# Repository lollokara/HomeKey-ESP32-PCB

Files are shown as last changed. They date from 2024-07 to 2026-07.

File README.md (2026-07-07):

<div align="center">

# HomeKey-ESP32-PCB

**A miniaturized, wall-mountable HomeKey reader board**

A custom PCB implementation of [rednblkx/HomeKey-ESP32](https://github.com/rednblkx/HomeKey-ESP32) that brings Apple HomeKey NFC unlocking into a form factor small enough to hide behind your existing wall plate.



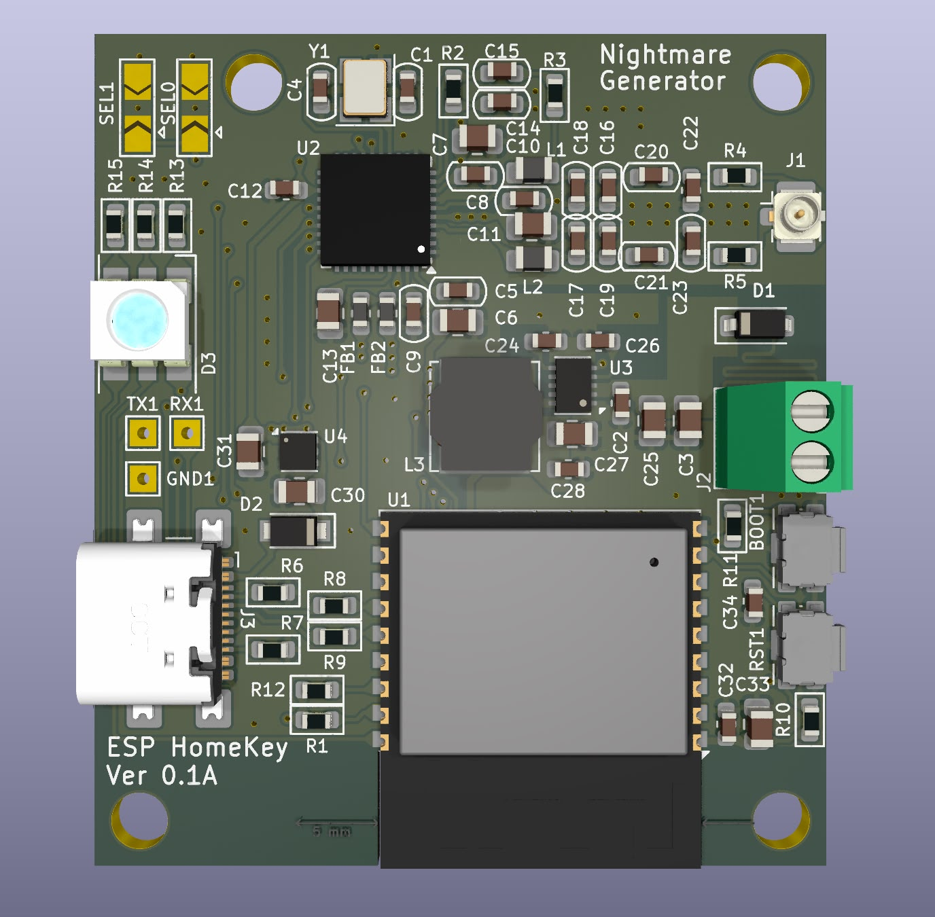
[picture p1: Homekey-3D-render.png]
HomeKey-ESP32-PCB 3D render


</div>

## What is this?

This project is a **hardware redesign** of the excellent [HomeKey-ESP32](https://github.com/rednblkx/HomeKey-ESP32) firmware by [@rednblkx](https://github.com/rednblkx). Instead of using a separate development board wired to a breakout PN532 module, everything is integrated onto a single, compact PCB.

The board packs an **ESP32-C3** and an **NFC reader front-end with an on-board coaxial NFC antenna** into a footprint designed to fit inside a **European 503 (3-module) flush-mount wall box**. This lets you install a fully functional Apple HomeKey reader directly behind a standard wall plate — no external modules, no messy wiring.

## Key Highlights

- **All-in-one PCB** — ESP32-C3 + NFC front-end + coaxial antenna on a single board
- **Fits a European 503 plug slot** — designed for standard flush-mount wall boxes
- **Integrated coaxial NFC antenna** — tuned on-board antenna, no external coil needed
- **Runs the original HomeKey-ESP32 firmware** — full Apple HomeKey / HomeKit compatibility
- **Fully open hardware** — designed in **KiCad**, with schematics, layout, Gerbers and a 3D model included

## Get the Board

Don't want to fabricate it yourself? You can order the PCB directly from PCBWay:

**➡️ [ESP32 HomeKey on PCBWay](https://www.pcbway.com/project/shareproject/ESP32_Homekey_77a119d7.html)**

## Designed in KiCad

The entire board is designed with **[KiCad](https://www.kicad.org/)**, so the complete hardware source is open and editable. The repository includes:

- Hierarchical KiCad schematics (`Homekey.kicad_sch`, `ESP32.kicad_sch`, `NFC.kicad_sch`, `Power.kicad_sch`, `Square.kicad_sch`)
- KiCad PCB layout (`Homekey.kicad_pcb`) and project file (`Homekey.kicad_pro`)
- Exported schematic PDF (`Homekey.pdf`)
- Bill of Materials (`Homekey.xlsx`)
- A 3D model of the assembly (`Homekey 3D.step.zip`)

You can open the project directly in KiCad to review, modify, or re-fabricate the board.

## Repository Structure

```
HomeKey-ESP32-PCB/
├── Firmware/              # HomeKey-ESP32 firmware (based on the original repo)
├── Gerbers/               # Fabrication-ready Gerber files
├── ESP32.kicad_sch        # ESP32-C3 subsheet
├── NFC.kicad_sch          # NFC front-end + antenna subsheet
├── Power.kicad_sch        # Power supply subsheet
├── Square.kicad_sch       # Additional subsheet
├── Homekey.kicad_sch      # Top-level schematic
├── Homekey.kicad_pcb      # PCB layout
├── Homekey.kicad_pro      # KiCad project file
├── Homekey.pdf            # Schematic (PDF export)
├── Homekey.xlsx           # Bill of Materials
├── Homekey-job.gbrjob     # Gerber job file
├── Homekey 3D.step.zip    # 3D model of the board
├── Homekey-3D-render.png  # 3D render of the assembled board
└── README.md
```

## Getting Started

### 1. Get the Board

- **Buy it ready-made:** order the PCB directly from [PCBWay](https://www.pcbway.com/project/shareproject/ESP32_Homekey_77a119d7.html).
- **Fabricate it yourself:** use the ready-to-order files in the [`Gerbers`](Gerbers) folder with your preferred PCB fab house.
- Refer to `Homekey.xlsx` for the Bill of Materials and `Homekey.pdf` for the schematic.
- To modify the design first, open `Homekey.kicad_pro` in KiCad.

### 2. Flash the Firmware

The board runs the standard HomeKey-ESP32 firmware. The [`Firmware`](Firmware) folder contains a build based on the original repository.

```bash
# Install esptool (one-time setup)
pip install esptool

# Flash the firmware (replace YOUR_PORT)
esptool.py --port YOUR_PORT write_flash 0x0 firmware.factory.bin
```

> Prefer a GUI? Use the [browser-based flasher](https://espressif.github.io/esptool-js/) — no command line needed.

For firmware configuration, pairing, and usage, follow the official documentation:
- **Docs:** https://rednblkx.github.io/HomeKey-ESP32/
- **Upstream firmware:** https://github.com/rednblkx/HomeKey-ESP32

### 3. Install & Pair

1. Mount the board inside your 503 wall box behind the plate.
2. Connect to the device's setup WiFi AP and configure your WiFi + HomeKit setup code.
3. Pair with Apple Home and start unlocking with a tap of your iPhone or Apple Watch. 🎉

## Credits

- **[@rednblkx](https://github.com/rednblkx)** — creator of the original [HomeKey-ESP32](https://github.com/rednblkx/HomeKey-ESP32) firmware this board is built for
- **[@kormax](https://github.com/kormax)** — reverse-engineered the HomeKey NFC protocol
- **[@kupa22](https://github.com/kupa22)** — researched the HAP side of HomeKey

## License

This project is licensed under the **MIT License** — see the [LICENSE](LICENSE) file for details.

## Disclaimer

This project implements Apple HomeKey functionality through reverse engineering.

- **Not affiliated** with, nor condoned by, Apple Inc.
- **Use at your own risk** for security-critical applications.
- **Apple**, **iPhone**, and **Apple Watch** are trademarks of Apple Inc.
- **ESP32** is a trademark of Espressif Systems (Shanghai) Co., Ltd.

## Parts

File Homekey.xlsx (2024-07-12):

Homekey
Id | Riferimento | Impronta | Quantità | Valore | Produttore | PN
1 | R9,R8 | R_0603_1608Metric | 2 | 22R 1% | Yageo | RC0603FR-0722RL
2 | C22 | C_0603_1608Metric | 1 | 100pF | Samsung | CL10B101KB8NFNC
3 | GND1,RX1,TX1 | TestPoint_THTPad_1.5x1.5mm_Drill0.7mm | 3 | TestPoint
4 | C30,C13,C27,C6,C31,C11,C10,C25,C3,C33 | C_0805_2012Metric | 10 | 10uF | Murata | CAP CER 10UF 50V X5R 0805
5 | R6,R7 | R_0603_1608Metric | 2 | 5K1 1% |  | RC0603FR-075K1L
6 | C15 | C_0603_1608Metric | 1 | 1nF | Kemet | C0603C102K5RAC7867
7 | C4,C1,C21,C20 | C_0603_1608Metric | 4 | 22pF | Kemet | C0603C220J5GAC7867
8 | U3 | TDFN-10-1EP_2x3mm_P0.5mm_EP0.9x2mm | 1 | MAX17501AxTB | Maxim | MAX17501AATB+T
9 | C32,C28,C2,C12 | C_0603_1608Metric | 4 | 100nF | Samsung | CL10B104KB8NNNC
10 | FB1,FB2 | L_0603_1608Metric | 2 | 220R@100Mhz | TDK | MPZ1608S221ATA00
11 | L1,L2 | L_0805_2012Metric | 2 | 560nH | Bourns | CV201210-R56K
12 | C24 | C_0603_1608Metric | 1 | 1nF | Kemet | C0603C102K5RAC7867
13 | D1 | SOD123 | 1 | MBR0560-TP | MCC | MBR0560-TP
14 | C7,C8,C5,C9,C14 | C_0603_1608Metric | 5 | 100nF | Samsung | CL10B104KB8NNNC
15 | R2 | R_0603_1608Metric | 1 | 1K 1% |  | RC0603FR-071K0L
16 | R11,R1,R10,R12 | R_0603_1608Metric | 4 | 10K |  | RC0603FR-0710KL
17 | C17,C16 | C_0603_1608Metric | 2 | 220pF | Samsung | CL10B221KB8NFNC
18 | RST1,BOOT1 | SW_SPST_CK_KMS2xxGP | 2 | CK_KMS2xxG | CK | KMS221GPLFS
19 | C19,C18 | C_0603_1608Metric | 2 | NC
20 | J1 | U.FL_Hirose_U.FL-R-SMT-1_Vertical | 1 | Hirose | Hirose | U.FL-R-SMT-1(32)
21 | U2 | HVQFN-40-1EP_6x6mm_P0.5mm_EP4.1x4.1mm | 1 | PN5321A3HN_C1xx | NXP | PN5321A3HN/C106,55
22 | R15,R13 | R_0603_1608Metric | 2 | 75R |  | RC0603FR-0775RL
23 | C26,C34 | C_0603_1608Metric | 2 | 1uF | Samsung | CL10B105KP8NNNC
24 | R5,R4 | R_0603_1608Metric | 2 | 1R5 1% |  | RC0603FR-071R5L
25 | L3 | L_Bourns_SRN6045TA | 1 | 33uH | Bourns | SRN6045TA-330M
26 | D2 | Nexperia_CFP3_SOD-123W | 1 | PMEG2010BER | Nexperia | PMEG2010BER
27 | D3 | LED_Inolux_IN-P55TATRGB_PLCC6_5.0x5.5mm_P1.8mm | 1 | Inolux_IN-P55TATRGB | Inolux | IN-P55TATRGB
28 | U4 | WSON-6-1EP_2x2mm_P0.65mm_EP1x1.6mm | 1 | TLV75533PDRV | Texas Instruments | TLV75533PDRV
29 | C23 | C_0603_1608Metric | 1 | 100pF | Samsung | CL10B101KB8NFNC
30 | J2 | TerminalBlock_Phoenix_MPT-0,5-2-2.54_1x02_P2.54mm_Horizontal | 1 | Screw_Terminal_01x02 | Phoenix | 1725656
31 | R14 | R_0603_1608Metric | 1 | 150R |  | RC0603FR-07150RL
32 | U1 | ESP32-C3-WROOM-02 | 1 | ESP32-C3-WROOM-02 | Espressif | ESP32-C3-WROOM-02-N4
33 | J3 | USB_C_Receptacle_GCT_USB4110 | 1 | USB_C_Receptacle_USB2.0_16P | GCT | USB4110-GF-A
34 | R3 | R_0603_1608Metric | 1 | 1K69 1% |  | RC0603FR-071K69L
35 | Y1 | Crystal_SMD_3225-4Pin_3.2x2.5mm | 1 | 27.12MHz | Raltron | RH100-27.120-12-F-3030-EXT-TR

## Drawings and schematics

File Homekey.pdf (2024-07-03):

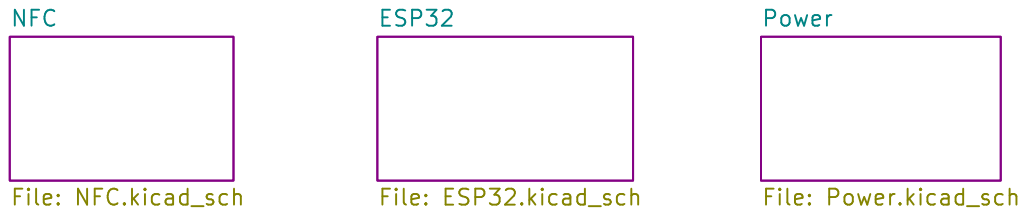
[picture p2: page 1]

File: Homekey.kicad_sch Sheet: /
Id: 1/4 Title: Homekey PCB ESP32C3

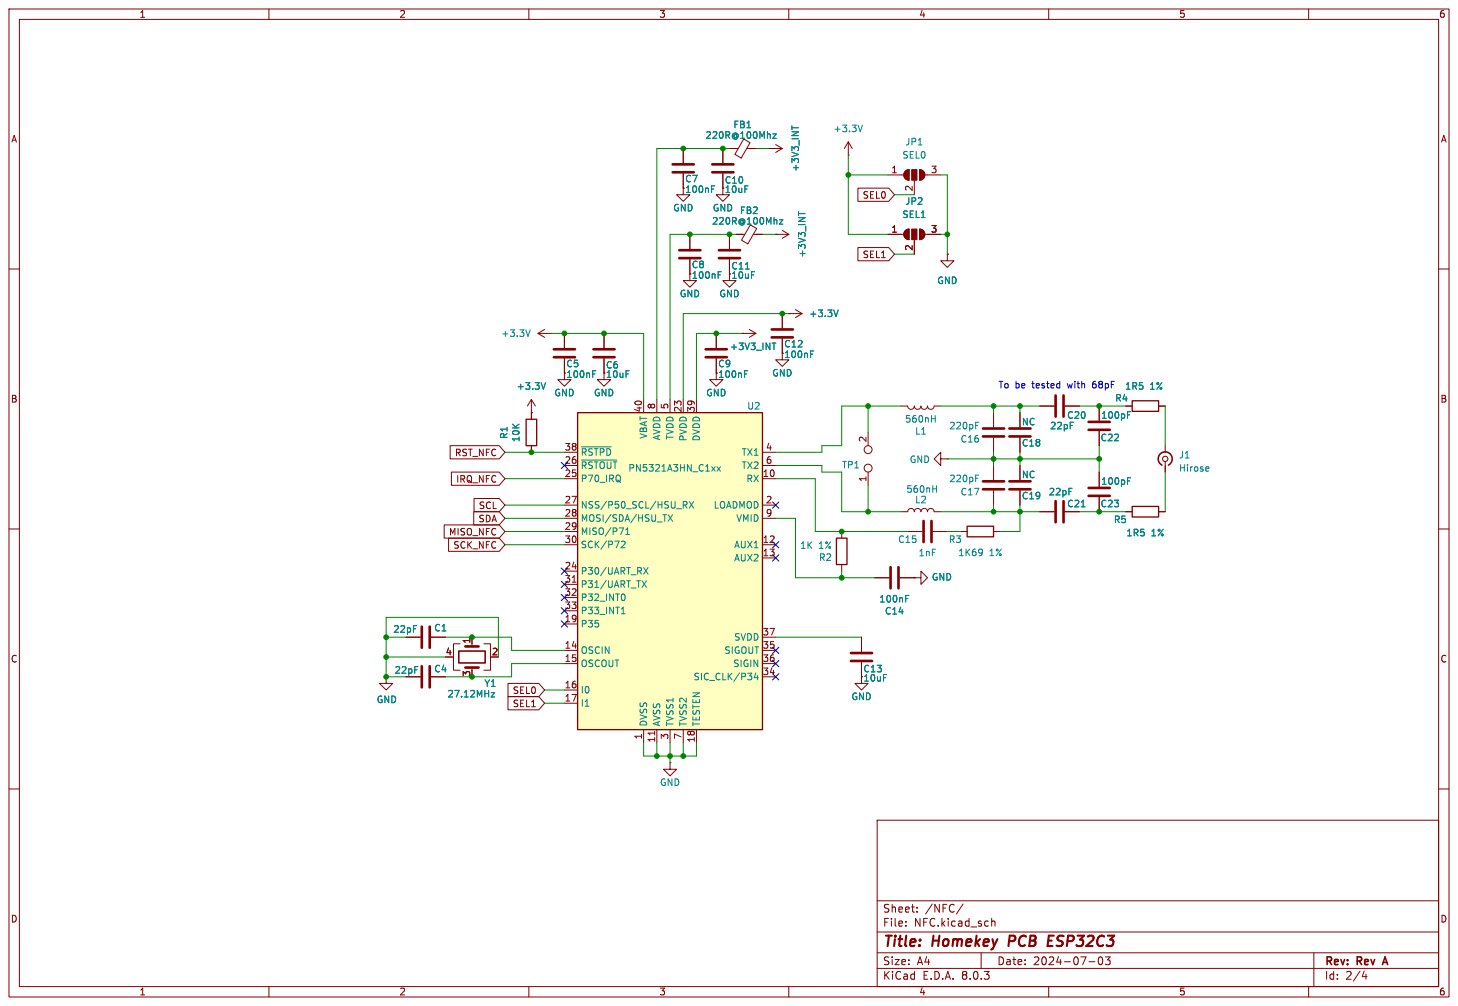
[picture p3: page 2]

Id: 2/4 Title: Homekey PCB ESP32C3

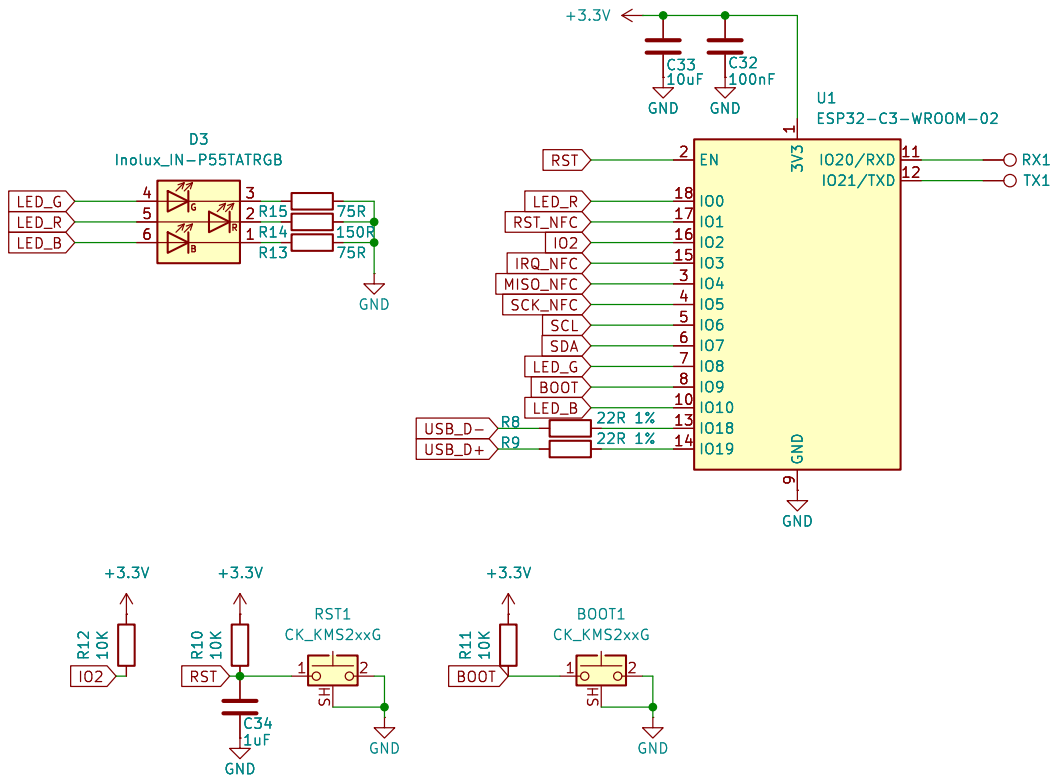
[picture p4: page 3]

Id: 3/4 Title: Homekey PCB ESP32C3

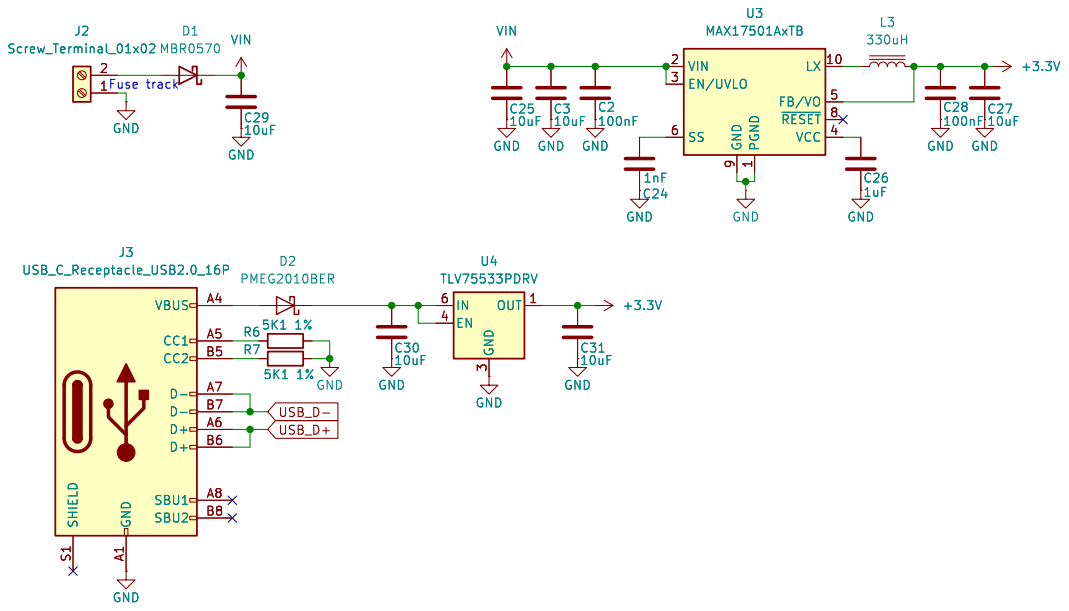
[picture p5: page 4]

File: Power.kicad_sch Sheet: /Power/
Id: 4/4 Title: Homekey PCB ESP32C3

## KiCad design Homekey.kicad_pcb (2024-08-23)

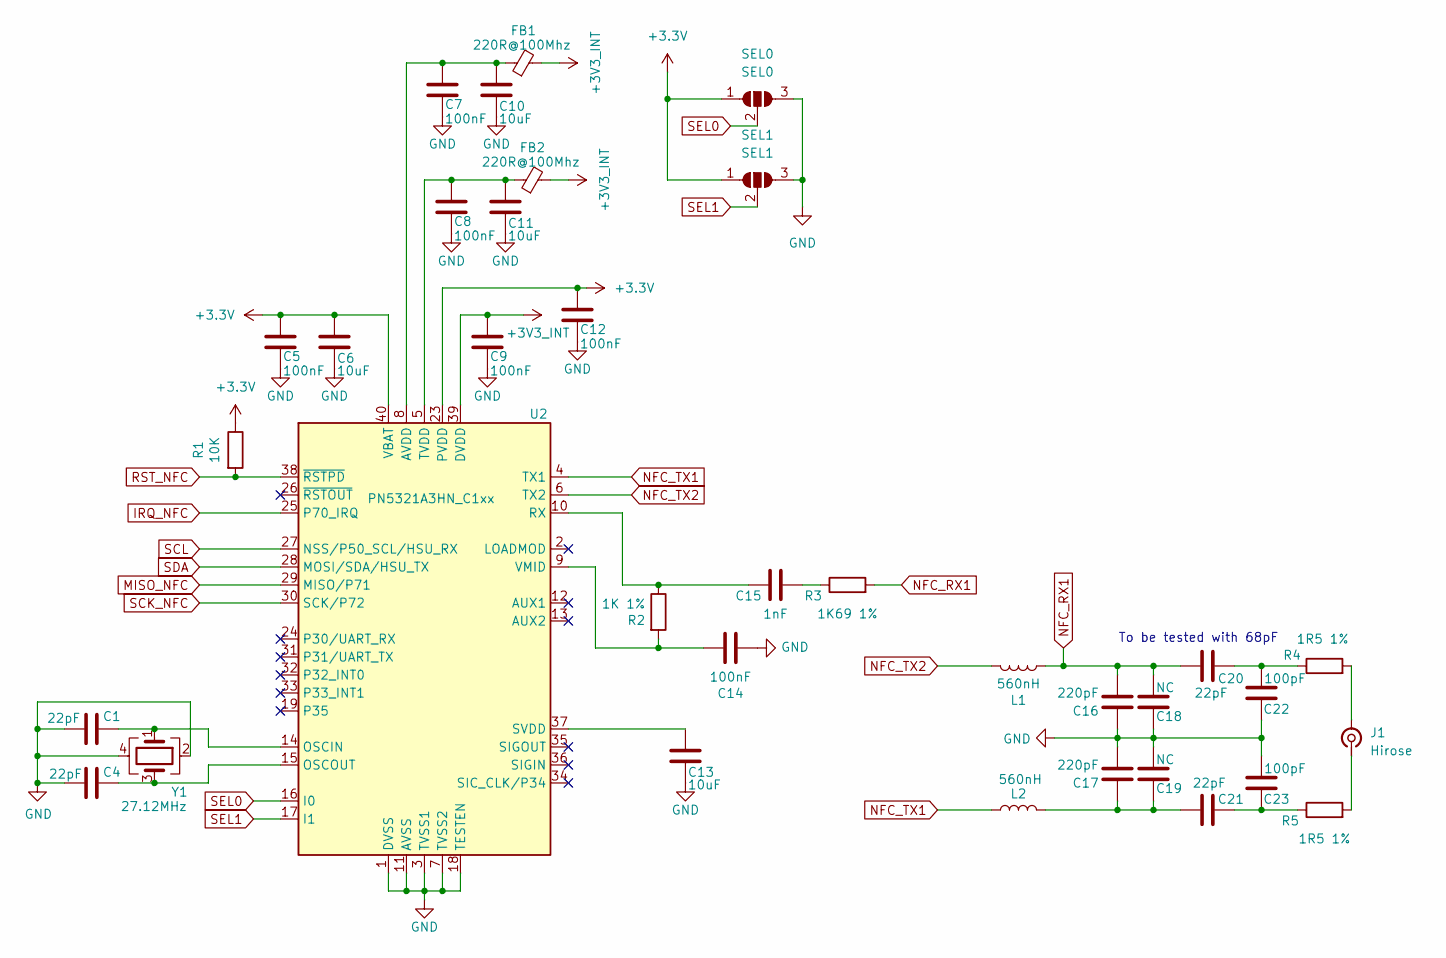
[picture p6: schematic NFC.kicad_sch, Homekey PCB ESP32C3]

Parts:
C1, C4: 22pF; C_0603_1608Metric; Part No 0603-22pF-50V
C5, C7, C8, C9, C12: 100nF; C_0603_1608Metric
C6, C10, C11, C13: 10uF; C_0805_2012Metric
C14: 100nF; C_0603_1608Metric; Part No 0603-100nF-25V
C15: 1nF; C_0603_1608Metric; Part No VJ0603A102GXAPW1BC
C16, C17: 220pF; C_0603_1608Metric; Part No 0603-220pF-50V
C18, C19: NC; C_0603_1608Metric
C20, C21: 22pF; C_0603_1608Metric; Part No 0603N220F500CT
C22, C23: 100pF; C_0603_1608Metric; Part No 0603-100pF-50V
FB1, FB2: 220R@100Mhz; L_0603_1608Metric
J1: Hirose; U.FL_Hirose_U.FL-R-SMT-1_Vertical
L1, L2: 560nH; L_0805_2012Metric; Part No LQW2UASR56G00L
R1: 10K; R_0603_1608Metric; Part No 0603-10K
R2: 1K 1%; R_0603_1608Metric; Part No CRCW06031K00FKEAC
R3: 1K69 1%; R_0603_1608Metric; Part No RC0603FR-101K69L
R4, R5: 1R5 1%; R_0603_1608Metric; Part No CRCW06031R50FKEA
SEL0: SEL0; SolderJumper-3_P2.0mm_Open_TrianglePad1.0x1.5mm
SEL1: SEL1; SolderJumper-3_P2.0mm_Open_TrianglePad1.0x1.5mm
U2: PN5321A3HN_C1xx; HVQFN-40-1EP_6x6mm_P0.5mm_EP4.1x4.1mm
Y1: 27.12MHz; Crystal_SMD_3225-4Pin_3.2x2.5mm; Part No ABM81-27.120MHZ-10-B1U-T3

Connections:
+3.3V: C5.2, C6.1, C12.2, R1.1, SEL0.1 (A), SEL1.1 (A), U2.23 (PVDD), U2.40 (VBAT); also elsewhere on the board
+3V3_INT: C9.2, FB1.2, FB2.2, U2.39 (DVDD)
GND: C1.2, C4.2, C5.1, C6.2, C7.1, C8.1, C9.1, C10.2, C11.2, C12.1, C13.2, C14.2, C16.1, C17.1, C18.1, C19.2, C22.1, C23.2, SEL0.3 (B), SEL1.3 (B), U2.1 (DVSS), U2.3 (TVSS1), U2.7 (TVSS2), U2.11 (AVSS), U2.18 (TESTEN), U2.41 (AVSS), Y1.2, Y1.4; also elsewhere on the board
IRQ_NFC: U2.25 (P70_IRQ); also elsewhere on the board
MISO_NFC: U2.29 (MISO/P71); also elsewhere on the board
NFC_RX1: C16.2, C18.2, C20.1, L1.1, R3.2
NFC_TX1: L2.1, U2.4 (TX1)
NFC_TX2: L1.2, U2.6 (TX2)
unnamed: C15.2, R3.1
unnamed: C17.2, C19.1, C21.1, L2.2
unnamed: C20.2, C22.2, R4.1
unnamed: C21.2, C23.1, R5.1
unnamed: J1.2 (Ext), R4.2
unnamed: J1.1 (In), R5.2
unnamed: C7.2, C10.1, FB1.1, U2.8 (AVDD)
unnamed: C1.1, U2.14 (OSCIN), Y1.1
unnamed: C4.1, U2.15 (OSCOUT), Y1.3
unnamed: C15.1, R2.1, U2.10 (RX)
unnamed: C13.1, U2.37 (SVDD)
unnamed: C8.2, C11.1, FB2.1, U2.5 (TVDD)
unnamed: C14.1, R2.2, U2.9 (VMID)
RST_NFC: R1.2, U2.38 (~RSTPD); also elsewhere on the board
SCK_NFC: U2.30 (SCK/P72); also elsewhere on the board
SCL: U2.27 (NSS/P50_SCL/HSU_RX); also elsewhere on the board
SDA: U2.28 (MOSI/SDA/HSU_TX); also elsewhere on the board
SEL0: SEL0.2 (C), U2.16 (I0)
SEL1: SEL1.2 (C), U2.17 (I1)

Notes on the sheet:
To be tested with 68pF

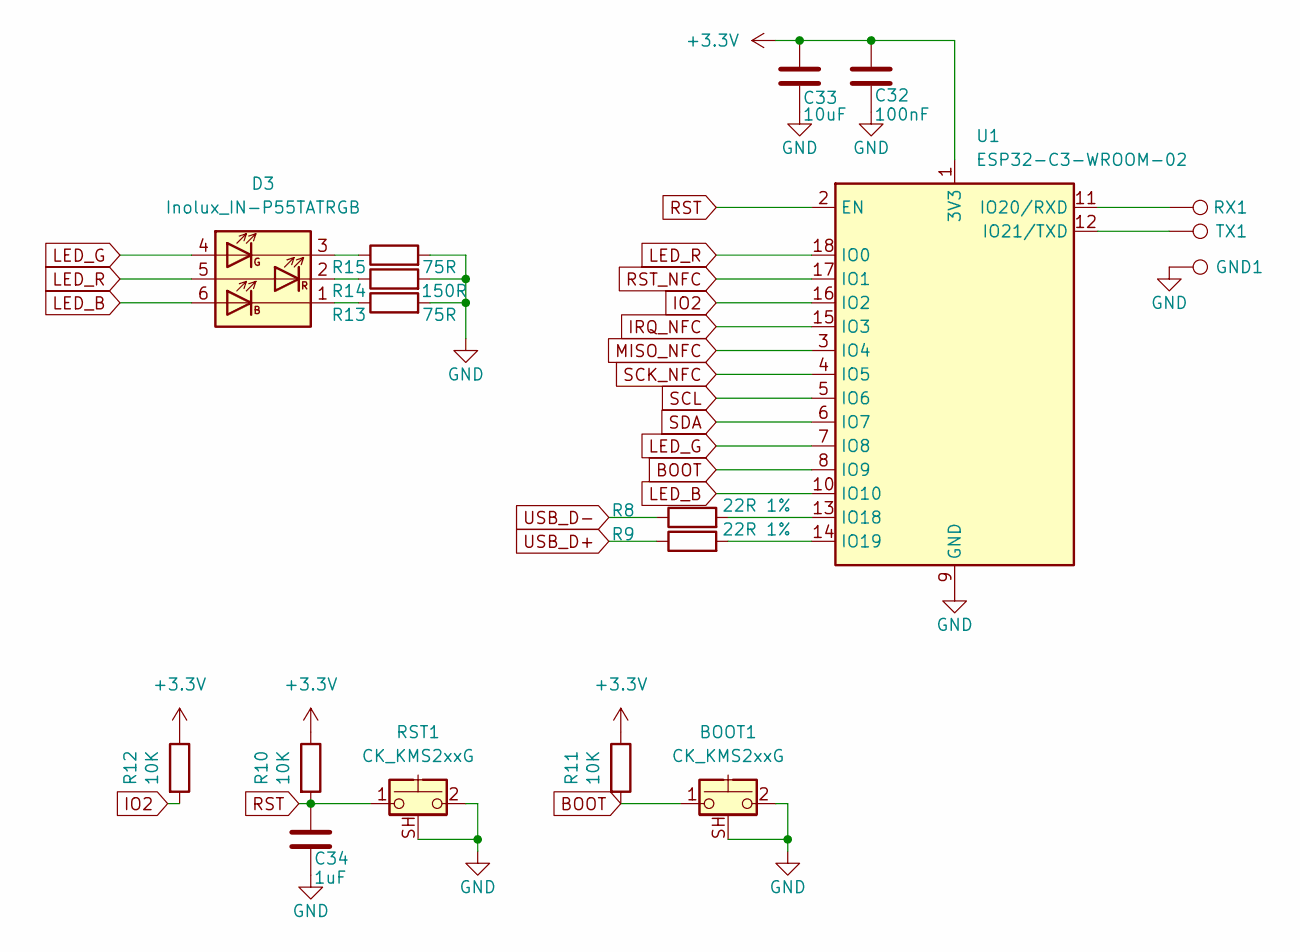
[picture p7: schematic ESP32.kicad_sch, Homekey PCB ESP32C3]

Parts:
BOOT1: CK_KMS2xxG; SW_SPST_CK_KMS2xxGP
C32: 100nF; C_0603_1608Metric
C33: 10uF; C_0805_2012Metric
C34: 1uF; C_0603_1608Metric
D3: Inolux_IN-P55TATRGB; LED_Inolux_IN-P55TATRGB_PLCC6_5.0x5.5mm_P1.8mm
GND1: TestPoint; TestPoint_THTPad_1.5x1.5mm_Drill0.7mm
R8, R9: 22R 1%; R_0603_1608Metric; Part No RC0603FR-1022RL
R10, R11, R12: 10K; R_0603_1608Metric; Part No 0603-10K
R13, R15: 75R; R_0603_1608Metric; Part No RC0603FR-0775RL
R14: 150R; R_0603_1608Metric; Part No RC0603JR-07160RL
RST1: CK_KMS2xxG; SW_SPST_CK_KMS2xxGP
RX1: TestPoint; TestPoint_THTPad_1.5x1.5mm_Drill0.7mm
TX1: TestPoint; TestPoint_THTPad_1.5x1.5mm_Drill0.7mm
U1: ESP32-C3-WROOM-02

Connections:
+3.3V: C32.2, C33.1, R10.1, R11.1, R12.1, U1.1 (3V3); also elsewhere on the board
BOOT: BOOT1.1, R11.2, U1.8 (IO9)
GND: BOOT1.2, BOOT1.SH (B), C32.1, C33.2, C34.1, GND1.1, R13.2, R14.2, R15.2, RST1.2, RST1.SH (B), U1.9 (GND), U1.19 (GND); also elsewhere on the board
IO2: R12.2, U1.16 (IO2)
IRQ_NFC: U1.15 (IO3); also elsewhere on the board
LED_B: D3.6 (AB), U1.10 (IO10)
LED_G: D3.4 (AG), U1.7 (IO8)
LED_R: D3.5 (AR), U1.18 (IO0)
MISO_NFC: U1.3 (IO4); also elsewhere on the board
unnamed: D3.1 (KB), R13.1
unnamed: D3.3 (KG), R15.1
unnamed: D3.2 (KR), R14.1
unnamed: R8.2, U1.13 (IO18)
unnamed: R9.2, U1.14 (IO19)
unnamed: RX1.1, U1.11 (IO20/RXD)
unnamed: TX1.1, U1.12 (IO21/TXD)
RST: C34.2, R10.2, RST1.1, U1.2 (EN)
RST_NFC: U1.17 (IO1); also elsewhere on the board
SCK_NFC: U1.4 (IO5); also elsewhere on the board
SCL: U1.5 (IO6); also elsewhere on the board
SDA: U1.6 (IO7); also elsewhere on the board
USB_D+: R9.1; also elsewhere on the board
USB_D-: R8.1; also elsewhere on the board

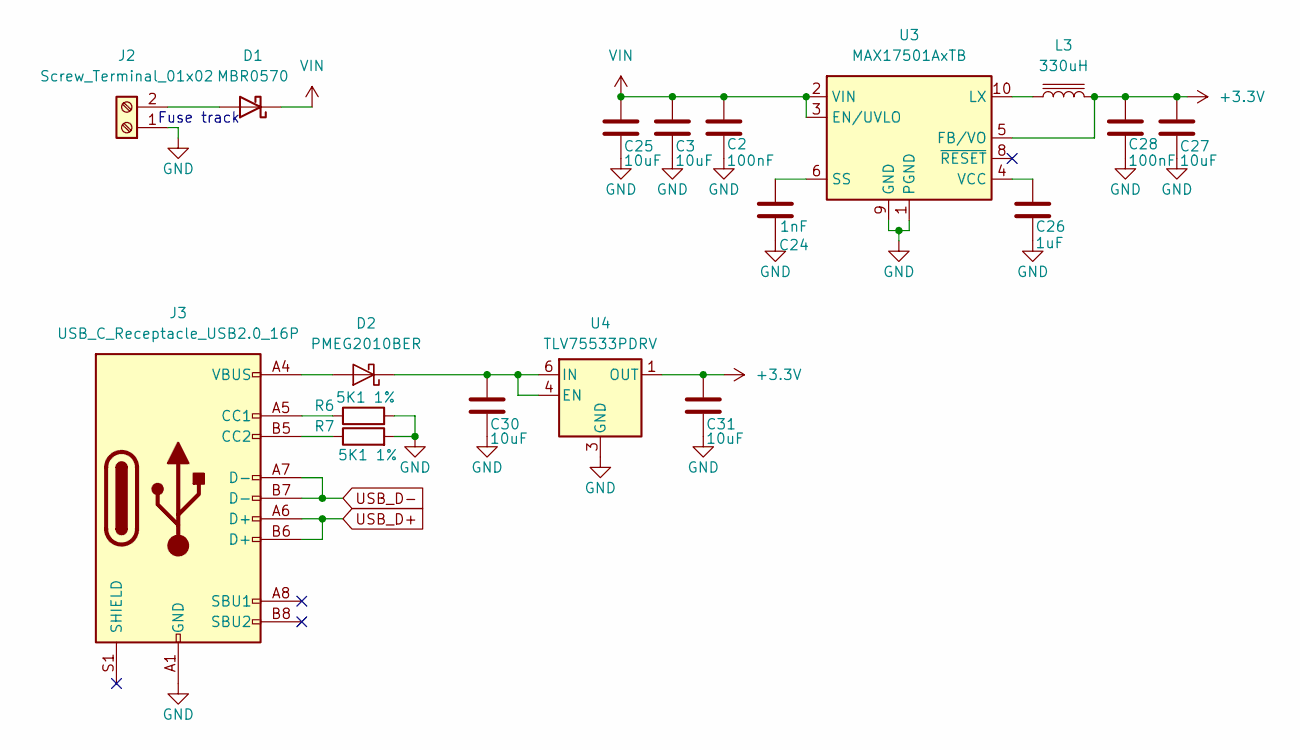
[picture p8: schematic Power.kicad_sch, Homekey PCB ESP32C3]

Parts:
C2, C28: 100nF; C_0603_1608Metric
C3, C25, C27, C30, C31: 10uF; C_0805_2012Metric
C24: 1nF; C_0603_1608Metric; Part No VJ0603A102GXAPW1BC
C26: 1uF; C_0603_1608Metric
D1: MBR0570; Fuseholder_Littelfuse_Nano2_157x
D2: PMEG2010BER; Nexperia_CFP3_SOD-123W
J2: Screw_Terminal_01x02; TerminalBlock_Phoenix_MPT-0,5-2-2.54_1x02_P2.54mm_Horizontal
J3: USB_C_Receptacle_USB2.0_16P; USB_C_Receptacle_GCT_USB4110
L3: 330uH; L_Bourns_SRN6045TA
R6, R7: 5K1 1%; R_0603_1608Metric; Part No RC0603FR-105K1L
U3: MAX17501AxTB; TDFN-10-1EP_2x3mm_P0.5mm_EP0.9x2mm
U4: TLV75533PDRV; WSON-6-1EP_2x2mm_P0.65mm_EP1x1.6mm

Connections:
+3.3V: C27.1, C28.2, C31.1, L3.2, U3.5 (FB/VO), U4.1 (OUT); also elsewhere on the board
GND: C2.1, C3.2, C24.1, C25.2, C26.1, C27.2, C28.1, C30.2, C31.2, J2.1, J3.A1 (GND), J3.A12 (GND), J3.B1 (GND), J3.B12 (GND), R6.2, R7.2, U3.1 (PGND), U3.9 (GND), U3.11 (GND), U4.3 (GND), U4.7 (GND); also elsewhere on the board
unnamed: D1.2 (A), J2.2
unnamed: D2.2 (A), J3.A4 (VBUS), J3.A9 (VBUS), J3.B4 (VBUS), J3.B9 (VBUS)
unnamed: C30.1, D2.1 (K), U4.4 (EN), U4.6 (IN)
unnamed: J3.A5 (CC1), R6.1
unnamed: J3.B5 (CC2), R7.1
unnamed: L3.1, U3.10 (LX)
unnamed: C24.2, U3.6 (SS)
unnamed: C26.2, U3.4 (VCC)
USB_D+: J3.A6 (D+), J3.B6 (D+); also elsewhere on the board
USB_D-: J3.A7 (D-), J3.B7 (D-); also elsewhere on the board
VIN: C2.2, C3.1, C25.1, D1.1 (K), U3.2 (VIN), U3.3 (EN/UVLO)

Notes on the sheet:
Fuse track

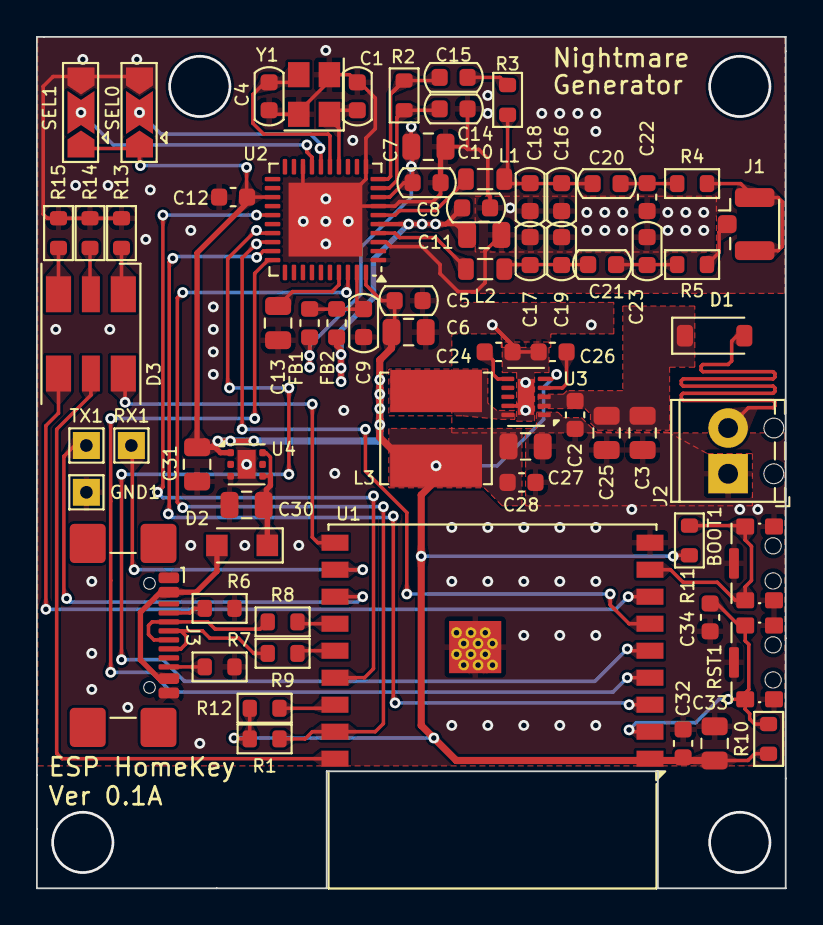
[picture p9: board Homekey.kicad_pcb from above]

Board: 2 copper layers, 41.6 x 47.3 mm, 71 parts (0 on the bottom side), 51 nets.

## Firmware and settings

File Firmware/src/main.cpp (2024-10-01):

#include <hkAuthContext.h>
#include <HomeKey.h>
#include <utils.h>
#include <HomeSpan.h>
#include <PN532_SPI.h>
#include <PN532.h>
#include <HAP.h>
#include <chrono>
#include <AsyncTCP.h>
#include <ESPAsyncWebServer.h>
#include <LittleFS.h>
#include <HK_HomeKit.h>
#include "config.h"
#include <mqtt_client.h>
#include <esp_ota_ops.h>
#include <esp_task.h>
#include <pins_arduino.h>
#include <Adafruit_NeoPixel.h>

const char* TAG = "MAIN";

enum lockStates
{
  UNLOCKED,
  LOCKED,
  JAMMED,
  UNKNOWN,
  UNLOCKING,
  LOCKING
};
AsyncWebServer webServer(80);
PN532_SPI pn532spi(6, 5, 4, 7);
PN532 nfc(pn532spi);
QueueHandle_t gpio_led_handle = nullptr;

nvs_handle savedData;
readerData_t readerData;
uint8_t ecpData[18] = { 0x6A, 0x2, 0xCB, 0x2, 0x6, 0x2, 0x11, 0x0 };
std::map<HK_COLOR, const char*> hk_color_vals = {{TAN, "AQTO1doA"}, {GOLD, "AQSq1uwA"}, {SILVER, "AQTj4+MA"}, {BLACK, "AQQAAAAA"}};
namespace espConfig
{
  struct mqttConfig_t
  {
    /* MQTT Broker */
    std::string mqttBroker = MQTT_HOST;
    uint16_t mqttPort = MQTT_PORT;
    std::string mqttUsername = MQTT_USERNAME;
    std::string mqttPassword = MQTT_PASSWORD;
    std::string mqttClientId = MQTT_CLIENTID;
    /* MQTT Topics */
    std::string hkTopic = MQTT_AUTH_TOPIC;
    std::string lockStateTopic = MQTT_STATE_TOPIC;
    std::string lockStateCmd = MQTT_SET_STATE_TOPIC;
    std::string lockCStateCmd = MQTT_SET_CURRENT_STATE_TOPIC;
    std::string lockTStateCmd = MQTT_SET_TARGET_STATE_TOPIC;
    /* MQTT Custom State */
    std::string lockCustomStateTopic = MQTT_CUSTOM_STATE_TOPIC;
    std::string lockCustomStateCmd = MQTT_CUSTOM_STATE_CTRL_TOPIC;
    /* Flags */
    bool lockEnableCustomState = MQTT_CUSTOM_STATE_ENABLED;
    bool hassMqttDiscoveryEnabled = MQTT_DISCOVERY;
    std::map<std::string, int> customLockStates = {{"C_LOCKED", C_LOCKED}, {"C_UNLOCKING", C_UNLOCKING}, {"C_UNLOCKED", C_UNLOCKED}, {"C_LOCKING", C_LOCKING}, {"C_JAMMED", C_JAMMED}, {"C_UNKNOWN", C_UNKNOWN}};
    std::map<std::string, int> customLockActions = {{"UNLOCK", UNLOCK}, {"LOCK", LOCK}};
  } mqttData;

  struct misc_config_t
  {
    std::string deviceName = DEVICE_NAME;
    std::string otaPasswd = OTA_PWD;
    uint8_t hk_key_color = HOMEKEY_COLOR;
    std::string setupCode = SETUP_CODE;
    bool lockAlwaysUnlock = HOMEKEY_ALWAYS_UNLOCK;
    bool lockAlwaysLock = HOMEKEY_ALWAYS_LOCK;
    uint8_t controlPin = HS_PIN;
    uint8_t hsStatusPin = HS_STATUS_LED;
    uint8_t nfcNeopixelPin = NFC_NEOPIXEL_PIN;
    uint8_t nfcSuccessPin = NFC_SUCCESS_PIN;
    uint16_t nfcSuccessTime = NFC_SUCCESS_TIME;
    bool nfcSuccessHL = NFC_SUCCESS_HL;
    uint8_t nfcFailPin = NFC_FAIL_PIN;
    uint16_t nfcFailTime = NFC_FAIL_TIME;
    bool nfcFailHL = NFC_FAIL_HL;
    bool gpioActionEnable = GPIO_ACTION_ENABLE;
    uint8_t gpioActionPin = GPIO_ACTION_PIN;
    bool gpioActionLockState = GPIO_ACTION_LOCK_STATE;
    bool gpioActionUnlockState = GPIO_ACTION_UNLOCK_STATE;
  } miscConfig;
}
JSONCONS_ALL_MEMBER_TRAITS(espConfig::mqttConfig_t, mqttBroker, mqttPort, mqttUsername, mqttPassword, mqttClientId, hkTopic, lockStateTopic, lockStateCmd, lockCStateCmd, lockTStateCmd, lockCustomStateTopic, lockCustomStateCmd, lockEnableCustomState, hassMqttDiscoveryEnabled, customLockStates, customLockActions)
JSONCONS_ALL_MEMBER_TRAITS(espConfig::misc_config_t, deviceName, hk_key_color, lockAlwaysUnlock, lockAlwaysLock, controlPin, hsStatusPin, nfcSuccessPin, nfcNeopixelPin, nfcSuccessHL, nfcFailPin, nfcFailHL, gpioActionEnable, gpioActionPin, gpioActionLockState, gpioActionUnlockState, otaPasswd, setupCode)

KeyFlow hkFlow = KeyFlow::kFlowFAST;
SpanCharacteristic* lockCurrentState;
SpanCharacteristic* lockTargetState;
esp_mqtt_client_handle_t client = nullptr;

Adafruit_NeoPixel pixels(1, espConfig::miscConfig.nfcNeopixelPin, NEO_GRB + NEO_KHZ800);

bool save_to_nvs() {
  std::vector<uint8_t> cborBuf;
  jsoncons::msgpack::encode_msgpack(readerData, cborBuf);
  esp_err_t set_nvs = nvs_set_blob(savedData, "READERDATA", cborBuf.data(), cborBuf.size());
  esp_err_t commit_nvs = nvs_commit(savedData);
  LOG(D, "NVS SET STATUS: %s", esp_err_to_name(set_nvs));
  LOG(D, "NVS COMMIT STATUS: %s", esp_err_to_name(commit_nvs));
  return !set_nvs && !commit_nvs;
}

struct LockManagement : Service::LockManagement
{
  SpanCharacteristic* lockControlPoint;
  SpanCharacteristic* version;
  const char* TAG = "LockManagement";

  LockManagement() : Service::LockManagement() {

    LOG(D, "Configuring LockManagement"); // initialization message

    lockControlPoint = new Characteristic::LockControlPoint();
    version = new Characteristic::Version();

  } // end constructor

}; // end LockManagement

// Function to calculate CRC16
void crc16a(unsigned char* data, unsigned int size, unsigned char* result) {
  unsigned short w_crc = 0x6363;

  for (unsigned int i = 0; i < size; ++i) {
    unsigned char byte = data[i];
    byte = (byte ^ (w_crc & 0x00FF));
    byte = ((byte ^ (byte << 4)) & 0xFF);
    w_crc = ((w_crc >> 8) ^ (byte << 8) ^ (byte << 3) ^ (byte >> 4)) & 0xFFFF;
  }

  result[0] = static_cast<unsigned char>(w_crc & 0xFF);
  result[1] = static_cast<unsigned char>((w_crc >> 8) & 0xFF);
}

// Function to append CRC16 to data
void with_crc16(unsigned char* data, unsigned int size, unsigned char* result) {
  crc16a(data, size, result);
}

struct LockMechanism : Service::LockMechanism
{
  const char* TAG = "LockMechanism";

  LockMechanism() : Service::LockMechanism() {
    LOG(I, "Configuring LockMechanism"); // initialization message
    lockCurrentState = new Characteristic::LockCurrentState(1, true);
    lockTargetState = new Characteristic::LockTargetState(1, true);
    memcpy(ecpData + 8, readerData.reader_gid.data(), readerData.reader_gid.size());
    with_crc16(ecpData, 16, ecpData + 16);
    if (espConfig::miscConfig.gpioActionEnable && espConfig::miscConfig.gpioActionPin != 255) {
      if (lockCurrentState->getVal() == lockStates::LOCKED) {
        digitalWrite(espConfig::miscConfig.gpioActionPin, espConfig::miscConfig.gpioActionLockState);
      }
      else if (lockCurrentState->getVal() == lockStates::UNLOCKED) {
        digitalWrite(espConfig::miscConfig.gpioActionPin, espConfig::miscConfig.gpioActionUnlockState);
      }
    }
  } // end constructor

  boolean update() {
    int targetState = lockTargetState->getNewVal();
    LOG(I, "New LockState=%d, Current LockState=%d", targetState, lockCurrentState->getVal());
    if (espConfig::miscConfig.gpioActionEnable && espConfig::miscConfig.gpioActionPin != 255) {
      switch (targetState)
      {
        case lockStates::UNLOCKED:
          digitalWrite(espConfig::miscConfig.gpioActionPin, espConfig::miscConfig.gpioActionUnlockState);
          lockCurrentState->setVal(lockStates::UNLOCKED);
          break;

        case lockStates::LOCKED:
          digitalWrite(espConfig::miscConfig.gpioActionPin, espConfig::miscConfig.gpioActionLockState);
          lockCurrentState->setVal(lockStates::LOCKED);
          break;

        default:
          break;
      }
    }
    int currentState = lockCurrentState->getNewVal();
    if (client != nullptr) {
      if (targetState != currentState) {
        esp_mqtt_client_publish(client, espConfig::mqttData.lockStateTopic.c_str(), targetState == lockStates::UNLOCKED ? std::to_string(lockStates::UNLOCKING).c_str() : std::to_string(lockStates::LOCKING).c_str(), 1, 1, true);
      }
      else {
        esp_mqtt_client_publish(client, espConfig::mqttData.lockStateTopic.c_str(), std::to_string(currentState).c_str(), 1, 1, true);
      }
      if (espConfig::mqttData.lockEnableCustomState) {
        if (targetState == lockStates::UNLOCKED) {
          esp_mqtt_client_publish(client, espConfig::mqttData.lockCustomStateTopic.c_str(), std::to_string(espConfig::mqttData.customLockActions["UNLOCK"]).c_str(), 0, 0, false);
        }
        else if (targetState == lockStates::LOCKED) {
          esp_mqtt_client_publish(client, espConfig::mqttData.lockCustomStateTopic.c_str(), std::to_string(espConfig::mqttData.customLockActions["LOCK"]).c_str(), 0, 0, false);
        }
      }
    }
    else LOG(W, "MQTT Client not initialized, cannot publish message");

    return (true);
  }
};

struct NFCAccess : Service::NFCAccess
{
  SpanCharacteristic* configurationState;
  SpanCharacteristic* nfcControlPoint;
  SpanCharacteristic* nfcSupportedConfiguration;
  const char* TAG = "NFCAccess";

  NFCAccess() : Service::NFCAccess() {
    LOG(I, "Configuring NFCAccess"); // initialization message
    configurationState = new Characteristic::ConfigurationState();
    nfcControlPoint = new Characteristic::NFCAccessControlPoint();
    TLV8 conf(NULL, 0);
    conf.add(0x01, 0x10);
    conf.add(0x02, 0x10);
    nfcSupportedConfiguration = new Characteristic::NFCAccessSupportedConfiguration(conf);
  }

  boolean update() {
    LOG(D, "PROVISIONED READER KEY: %s", utils::bufToHexString(readerData.reader_pk.data(), readerData.reader_pk.size()).c_str());
    LOG(D, "READER GROUP IDENTIFIER: %s", utils::bufToHexString(readerData.reader_gid.data(), readerData.reader_gid.size()).c_str());
    LOG(D, "READER UNIQUE IDENTIFIER: %s", utils::bufToHexString(readerData.reader_id.data(), readerData.reader_id.size()).c_str());

    TLV8 ctrlData(NULL, 0);
    nfcControlPoint->getNewTLV(ctrlData);
    std::vector<uint8_t> tlvData(ctrlData.pack_size());
    ctrlData.pack(tlvData.data());
    if (tlvData.size() == 0)
      return false;
    LOG(D, "Decoded data: %s", utils::bufToHexString(tlvData.data(), tlvData.size()).c_str());
    LOG(D, "Decoded data length: %d", tlvData.size());
    HK_HomeKit hkCtx(readerData, savedData, "READERDATA", tlvData);
    std::vector<uint8_t> result = hkCtx.processResult();
    if (readerData.reader_gid.size() > 0) {
      memcpy(ecpData + 8, readerData.reader_gid.data(), readerData.reader_gid.size());
      with_crc16(ecpData, 16, ecpData + 16);
    }
    TLV8 res(NULL, 0);
    res.unpack(result.data(), result.size());
    nfcControlPoint->setTLV(res, false);
    return true;
  }

};

void deleteReaderData(const char* buf) {
  esp_err_t erase_nvs = nvs_erase_key(savedData, "READERDATA");
  esp_err_t commit_nvs = nvs_commit(savedData);
  readerData.issuers.clear();
  readerData.reader_gid.clear();
  readerData.reader_id.clear();
  readerData.reader_pk.clear();
  readerData.reader_pk_x.clear();
  readerData.reader_sk.clear();
  LOG(D, "*** NVS W STATUS");
  LOG(D, "ERASE: %s", esp_err_to_name(erase_nvs));
  LOG(D, "COMMIT: %s", esp_err_to_name(commit_nvs));
  LOG(D, "*** NVS W STATUS");
}

void pairCallback() {
  if (HAPClient::nAdminControllers() == 0) {
    deleteReaderData(NULL);
    return;
  }
  for (auto it = homeSpan.controllerListBegin(); it != homeSpan.controllerListEnd(); ++it) {
    std::vector<uint8_t> id = utils::getHashIdentifier(it->getLTPK(), 32, true);
    LOG(D, "Found allocated controller - Hash: %s", utils::bufToHexString(id.data(), 8).c_str());
    hkIssuer_t* foundIssuer = nullptr;
    for (auto&& issuer : readerData.issuers) {
      if (std::equal(issuer.issuer_id.begin(), issuer.issuer_id.end(), id.begin())) {
        LOG(D, "Issuer %s already added, skipping", utils::bufToHexString(issuer.issuer_id.data(), issuer.issuer_id.size()).c_str());
        foundIssuer = &issuer;
        break;
      }
    }
    if (foundIssuer == nullptr) {
      LOG(D, "Adding new issuer - ID: %s", utils::bufToHexString(id.data(), 8).c_str());
      hkIssuer_t newIssuer;
      newIssuer.issuer_id = std::vector<uint8_t>{id.begin(), id.begin() + 8};
      newIssuer.issuer_pk.insert(newIssuer.issuer_pk.begin(), it->getLTPK(), it->getLTPK() + 32);
      readerData.issuers.emplace_back(newIssuer);
    }
  }
  save_to_nvs();
}

void setFlow(const char* buf) {
  switch (buf[1]) {
  case '0':
    hkFlow = KeyFlow::kFlowFAST;
    Serial.println("FAST Flow");
    break;

  case '1':
    hkFlow = KeyFlow::kFlowSTANDARD;
    Serial.println("STANDARD Flow");
    break;
  case '2':
    hkFlow = KeyFlow::kFlowATTESTATION;
    Serial.println("ATTESTATION Flow");
    break;

  default:
    Serial.println("0 = FAST flow, 1 = STANDARD Flow, 2 = ATTESTATION Flow");
    break;
  }
}

void setLogLevel(const char* buf) {
  esp_log_level_t level = esp_log_level_get("*");
  if (strncmp(buf + 1, "E", 1) == 0) {
    level = ESP_LOG_ERROR;
    Serial.println("ERROR");
  }
  else if (strncmp(buf + 1, "W", 1) == 0) {
    level = ESP_LOG_WARN;
    Serial.println("WARNING");
  }
  else if (strncmp(buf + 1, "I", 1) == 0) {
    level = ESP_LOG_INFO;
    Serial.println("INFO");
  }
  else if (strncmp(buf + 1, "D", 1) == 0) {
    level = ESP_LOG_DEBUG;
    Serial.println("DEBUG");
  }
  else if (strncmp(buf + 1, "V", 1) == 0) {
    level = ESP_LOG_VERBOSE;
    Serial.println("VERBOSE");
  }
  else if (strncmp(buf + 1, "N", 1) == 0) {
    level = ESP_LOG_NONE;
    Serial.println("NONE");
  }

  esp_log_level_set(TAG, level);
  esp_log_level_set("HK_HomeKit", level);
  esp_log_level_set("HKAuthCtx", level);
  esp_log_level_set("HKFastAuth", level);
  esp_log_level_set("HKStdAuth", level);
  esp_log_level_set("HKAttestAuth", level);
  esp_log_level_set("PN532", level);
  esp_log_level_set("PN532_SPI", level);
  esp_log_level_set("ISO18013_SC", level);
  esp_log_level_set("LockMechanism", level);
  esp_log_level_set("NFCAccess", level);
}

void print_issuers(const char* buf) {
  for (auto&& issuer : readerData.issuers) {
    LOG(I, "Issuer ID: %s, Public Key: %s", utils::bufToHexString(issuer.issuer_id.data(), issuer.issuer_id.size()).c_str(), utils::bufToHexString(issuer.issuer_pk.data(), issuer.issuer_pk.size()).c_str());
    for (auto&& endpoint : issuer.endpoints) {
      LOG(I, "Endpoint ID: %s, Public Key: %s", utils::bufToHexString(endpoint.endpoint_id.data(), endpoint.endpoint_id.size()).c_str(), utils::bufToHexString(endpoint.endpoint_pk.data(), endpoint.endpoint_pk.size()).c_str());
    }
  }
}

/**
 * The function `set_custom_state_handler` translate the custom states to their HomeKit counterpart
 * updating the state of the lock and publishes the new state to the `MQTT_STATE_TOPIC` MQTT topic.
 *
 * @param client The `client` parameter in the `set_custom_state_handler` function is of type
 * `esp_mqtt_client_handle_t`, which is a handle to the MQTT client object for this event. This
 * parameter is used to interact with the MQTT client
 * @param state The `state` parameter in the `set_custom_state_handler` function represents the
 *  received custom state value
 */
void set_custom_state_handler(esp_mqtt_client_handle_t client, int state) {
  if(espConfig::mqttData.customLockStates["C_UNLOCKING"] == state){
    lockTargetState->setVal(lockStates::UNLOCKED);
    esp_mqtt_client_publish(client, espConfig::mqttData.lockStateTopic.c_str(), std::to_string(lockStates::UNLOCKING).c_str(), 0, 1, true);
    return;
  }
  else if (espConfig::mqttData.customLockStates["C_LOCKING"] == state) {
    lockTargetState->setVal(lockStates::LOCKED);
    esp_mqtt_client_publish(client, espConfig::mqttData.lockStateTopic.c_str(), std::to_string(lockStates::LOCKING).c_str(), 0, 1, true);
    return;
  }
  else if (espConfig::mqttData.customLockStates["C_UNLOCKED"] == state) {
    if (espConfig::miscConfig.gpioActionEnable && espConfig::miscConfig.gpioActionPin != 0) {
      digitalWrite(espConfig::miscConfig.gpioActionPin, espConfig::miscConfig.gpioActionUnlockState);
    }
    lockCurrentState->setVal(lockStates::UNLOCKED);
    esp_mqtt_client_publish(client, espConfig::mqttData.lockStateTopic.c_str(), std::to_string(lockStates::UNLOCKED).c_str(), 0, 1, true);
    return;
  }
  else if (espConfig::mqttData.customLockStates["C_LOCKED"] == state) {
    if (espConfig::miscConfig.gpioActionEnable && espConfig::miscConfig.gpioActionPin != 0) {
      digitalWrite(espConfig::miscConfig.gpioActionPin, espConfig::miscConfig.gpioActionLockState);
    }
    lockCurrentState->setVal(lockStates::LOCKED);
    esp_mqtt_client_publish(client, espConfig::mqttData.lockStateTopic.c_str(), std::to_string(lockStates::LOCKED).c_str(), 0, 1, true);
    return;
  }
  else if (espConfig::mqttData.customLockStates["C_JAMMED"] == state) {
    lockCurrentState->setVal(lockStates::JAMMED);
    esp_mqtt_client_publish(client, espConfig::mqttData.lockStateTopic.c_str(), std::to_string(lockStates::JAMMED).c_str(), 0, 1, true);
    return;
  }
  else if (espConfig::mqttData.customLockStates["C_UNKNOWN"] == state) {
    lockCurrentState->setVal(lockStates::UNKNOWN);
    esp_mqtt_client_publish(client, espConfig::mqttData.lockStateTopic.c_str(), std::to_string(lockStates::UNKNOWN).c_str(), 0, 1, true);
    return;
  }
  LOG(D, "Update state failed! Recv value not valid");
}

void set_state_handler(esp_mqtt_client_handle_t client, int state) {
  switch (state) {
  case lockStates::UNLOCKED:
    if (espConfig::miscConfig.gpioActionEnable && espConfig::miscConfig.gpioActionPin != 255) {
      digitalWrite(espConfig::miscConfig.gpioActionPin, espConfig::miscConfig.gpioActionUnlockState);
    }
    lockTargetState->setVal(state);
    lockCurrentState->setVal(state);
    esp_mqtt_client_publish(client, espConfig::mqttData.lockStateTopic.c_str(), std::to_string(lockStates::UNLOCKED).c_str(), 0, 1, true);
    if (espConfig::mqttData.lockEnableCustomState) {
      esp_mqtt_client_publish(client, espConfig::mqttData.lockCustomStateTopic.c_str(), std::to_string(espConfig::mqttData.customLockActions["UNLOCK"]).c_str(), 0, 0, false);
    }
    break;
  case lockStates::LOCKED:
    if (espConfig::miscConfig.gpioActionEnable && espConfig::miscConfig.gpioActionPin != 255) {
      digitalWrite(espConfig::miscConfig.gpioActionPin, espConfig::miscConfig.gpioActionLockState);
    }
    lockTargetState->setVal(state);
    lockCurrentState->setVal(state);
    esp_mqtt_client_publish(client, espConfig::mqttData.lockStateTopic.c_str(), std::to_string(lockStates::LOCKED).c_str(), 0, 1, true);
    if (espConfig::mqttData.lockEnableCustomState) {
      esp_mqtt_client_publish(client, espConfig::mqttData.lockCustomStateTopic.c_str(), std::to_string(espConfig::mqttData.customLockActions["LOCK"]).c_str(), 0, 0, false);
    }
    break;
  case lockStates::JAMMED:
  case lockStates::UNKNOWN:
    lockCurrentState->setVal(state);
    esp_mqtt_client_publish(client, espConfig::mqttData.lockStateTopic.c_str(), std::to_string(state).c_str(), 0, 1, true);
    break;
  default:
    LOG(D, "Update state failed! Recv value not valid");
    break;
  }
}
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
void loop() {
}

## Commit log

2024-07-03 Initial Push :)
    [ESP32.kicad_sch, Homekey.kicad_pcb, Homekey.kicad_sch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]
2024-07-03 Concluded ESP32 + Power
    still need to have a look around for errors
    [ESP32.kicad_sch, NFC.kicad_sch, Power.kicad_sch]
2024-07-03 Added Revs + PDF
    [ESP32.kicad_sch, Homekey.kicad_sch, NFC.kicad_sch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]
2024-07-09 Start of layout
    [ESP32.kicad_sch, Homekey.kicad_pcb, NFC.kicad_sch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]
2024-07-09 Finished rev A PCB V 0.1
    [ESP32.kicad_sch, Homekey.kicad_pcb, NFC.kicad_sch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]
2024-07-12 Adding gerbers + BOM
    [Homekey-B_Cu.gbr, Homekey-B_Mask.gbr, Homekey-B_Paste.gbr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]
2024-08-02 Added centroid files for PNP
    [Homekey-all-pos.xlsx]
2024-08-21 Added Teardops to the various connection, repoured polys, updated gerbers
    [Homekey-B_Cu.gbr, Homekey-B_Mask.gbr, Homekey-B_Paste.gbr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]
2024-08-23 Added 3D Model
    [Homekey.kicad_pcb]
2024-09-24 Fixed SS problem, bumped C24 to 3300pF
    [Homekey.xlsx, Power.kicad_sch]
2026-07-07 Updated Image of the PCB

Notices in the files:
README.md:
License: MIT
